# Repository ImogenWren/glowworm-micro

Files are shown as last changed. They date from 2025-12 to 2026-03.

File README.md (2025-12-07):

glowworm-logo-export

# glowworm-micro

Project to build a small battery powered handheld lighting controller for creative macro photography

## Project Due Data: 25/12/25

## Desired Features
- Arduino IoT33 Controller (could be ported to ESP32)
- 1S Lipo battery pack with charger
- Power on and off device using external interrupts
- Rotary Encoder for changing values

- Buttons to select parameter
- Detachable WS2821 Led Strip with 3D printed diffuser options
- 3D printed & ergonomic case
- fastLED library

- 2 Channel Lighting, each channel will have independent
    - Hue
    - Saturation
    - Brightness

Additional control ->  blend mode
- Unblended -> Colours remain seperate
- Direct Blend ->  blend will mix colours directly  
- Colour wheel short blend -> two channels will blend via the shortest route around the colour wheel between them
- colour wheel long blend -> two channels will blend via the longest path around the colour wheel

## Strech Goals
- Save & Recall current settings on shutdown/powerup
- OLED screen displaying all parameters
- highlight currently selected parameter
- Battery indicator
- PCB for control system
- PCB for LED Strip
- Advanced colour palettes



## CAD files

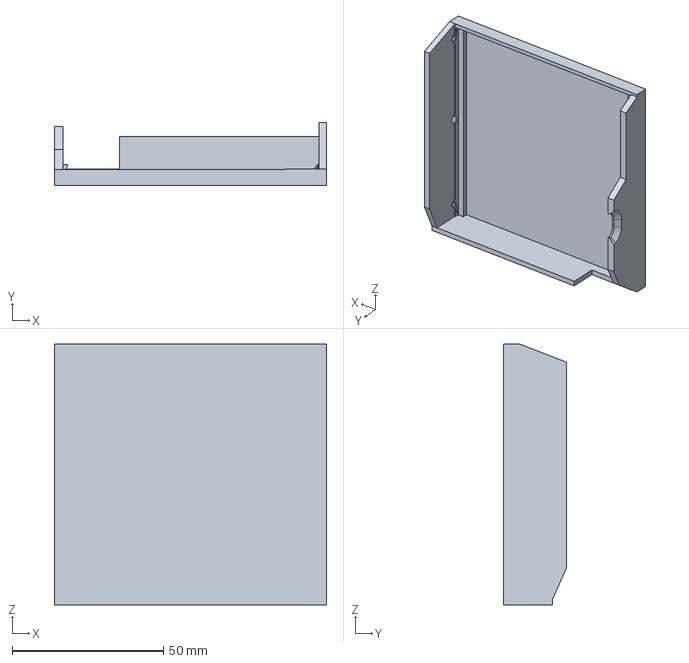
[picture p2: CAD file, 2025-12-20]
CAD/prototyping/glowworm-case-bottom.stp
89.8 x 20.9 x 86.2 mm

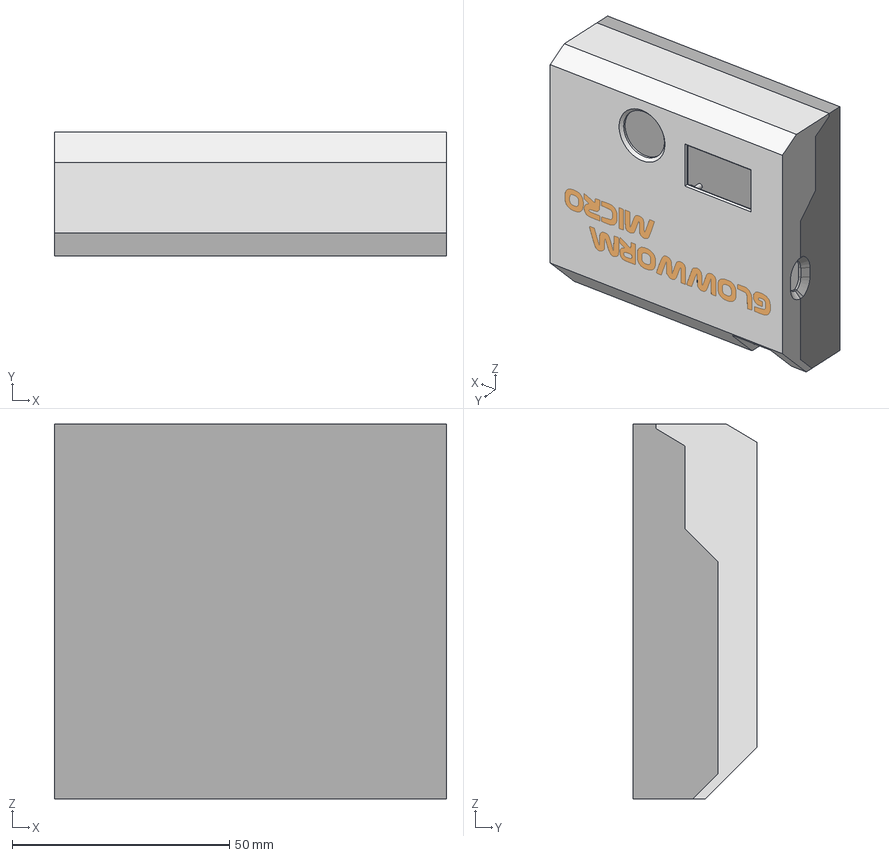
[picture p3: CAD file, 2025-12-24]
CAD/V3-glowworm-CAD.stp
90.2 x 28.5 x 86.2 mm

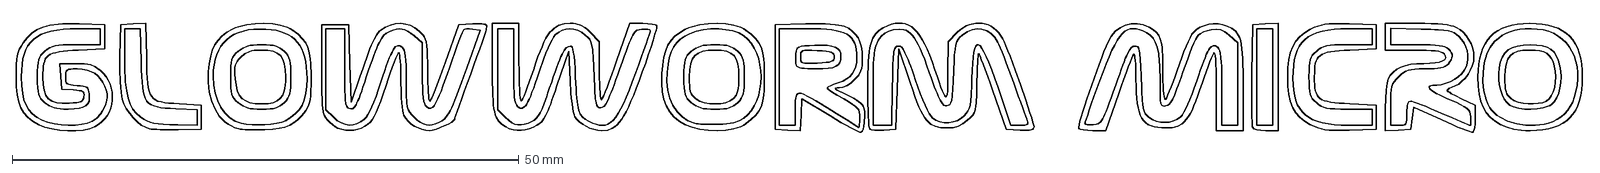
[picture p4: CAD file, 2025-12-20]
docs/glowworm-logo.dxf
154.7 x 11.5 mm

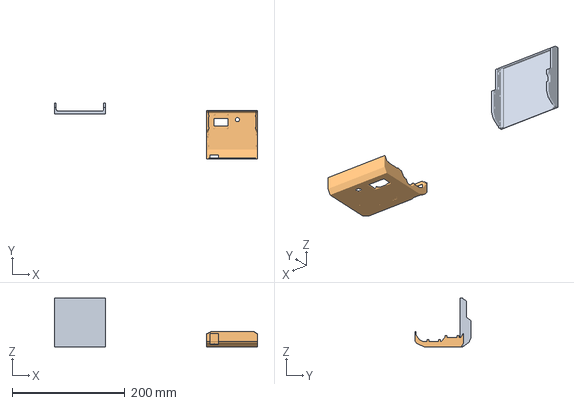
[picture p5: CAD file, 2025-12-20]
CAD/glowworm-case-test-print.3mf
360.3 x 99.0 x 86.2 mm

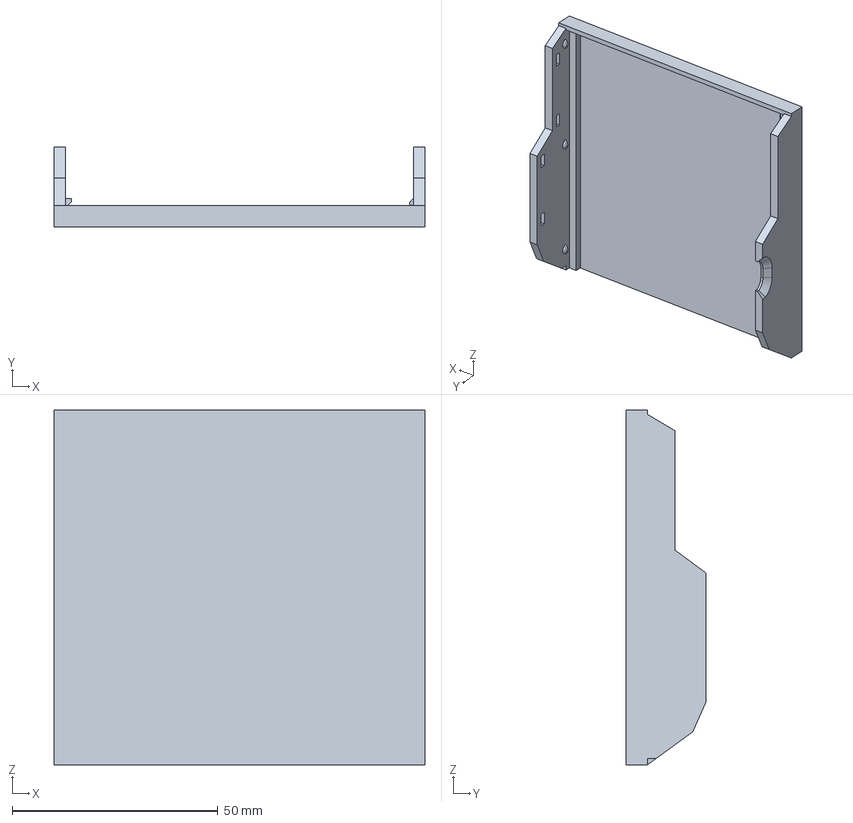
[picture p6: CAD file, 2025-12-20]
CAD/glowworm-case-bottom-V1.stp
90.2 x 19.5 x 86.2 mm

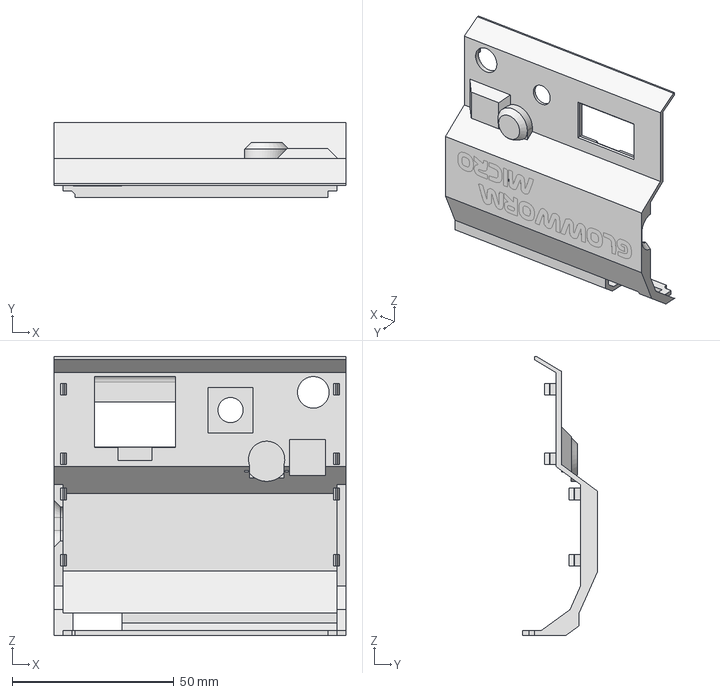
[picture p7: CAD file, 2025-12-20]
CAD/glowworm-case-lid-V1.stp
90.2 x 23.1 x 86.2 mm

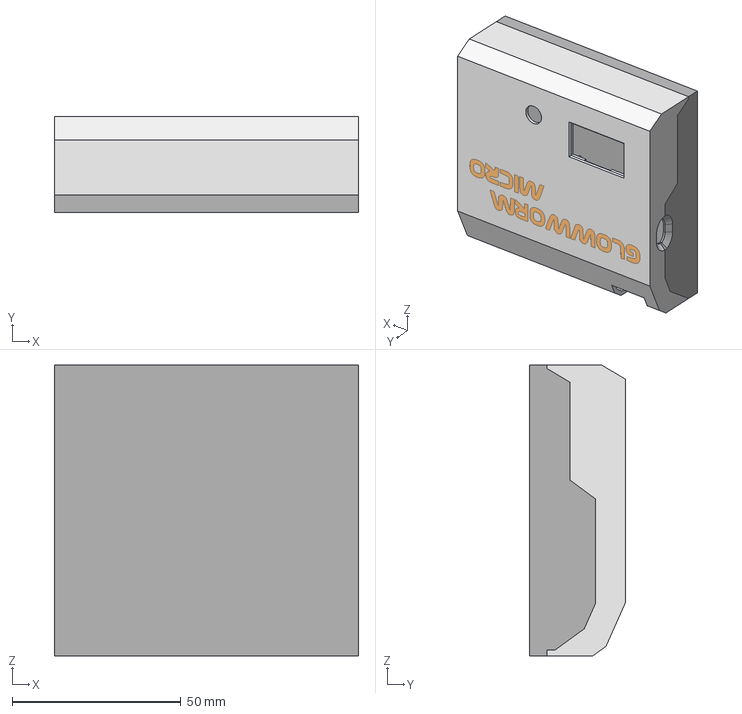
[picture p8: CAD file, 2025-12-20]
CAD/V2-glowworm-case.stp
90.2 x 28.5 x 86.2 mm

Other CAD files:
CAD/OldVersions/V2-glowworm-CAD.0008.ipt
CAD/OldVersions/V3-glowworm-CAD.0017.ipt
CAD/OldVersions/glowworm-CAD.0032.ipt
CAD/V2-glowworm-CAD.ipt
CAD/V2-glowworm-case.3mf
CAD/V3-glowworm-CAD.3mf
CAD/V3-glowworm-CAD.ipt
CAD/glowworm-CAD.ipt
CAD/prototyping/glowworm-case-bottom.3mf

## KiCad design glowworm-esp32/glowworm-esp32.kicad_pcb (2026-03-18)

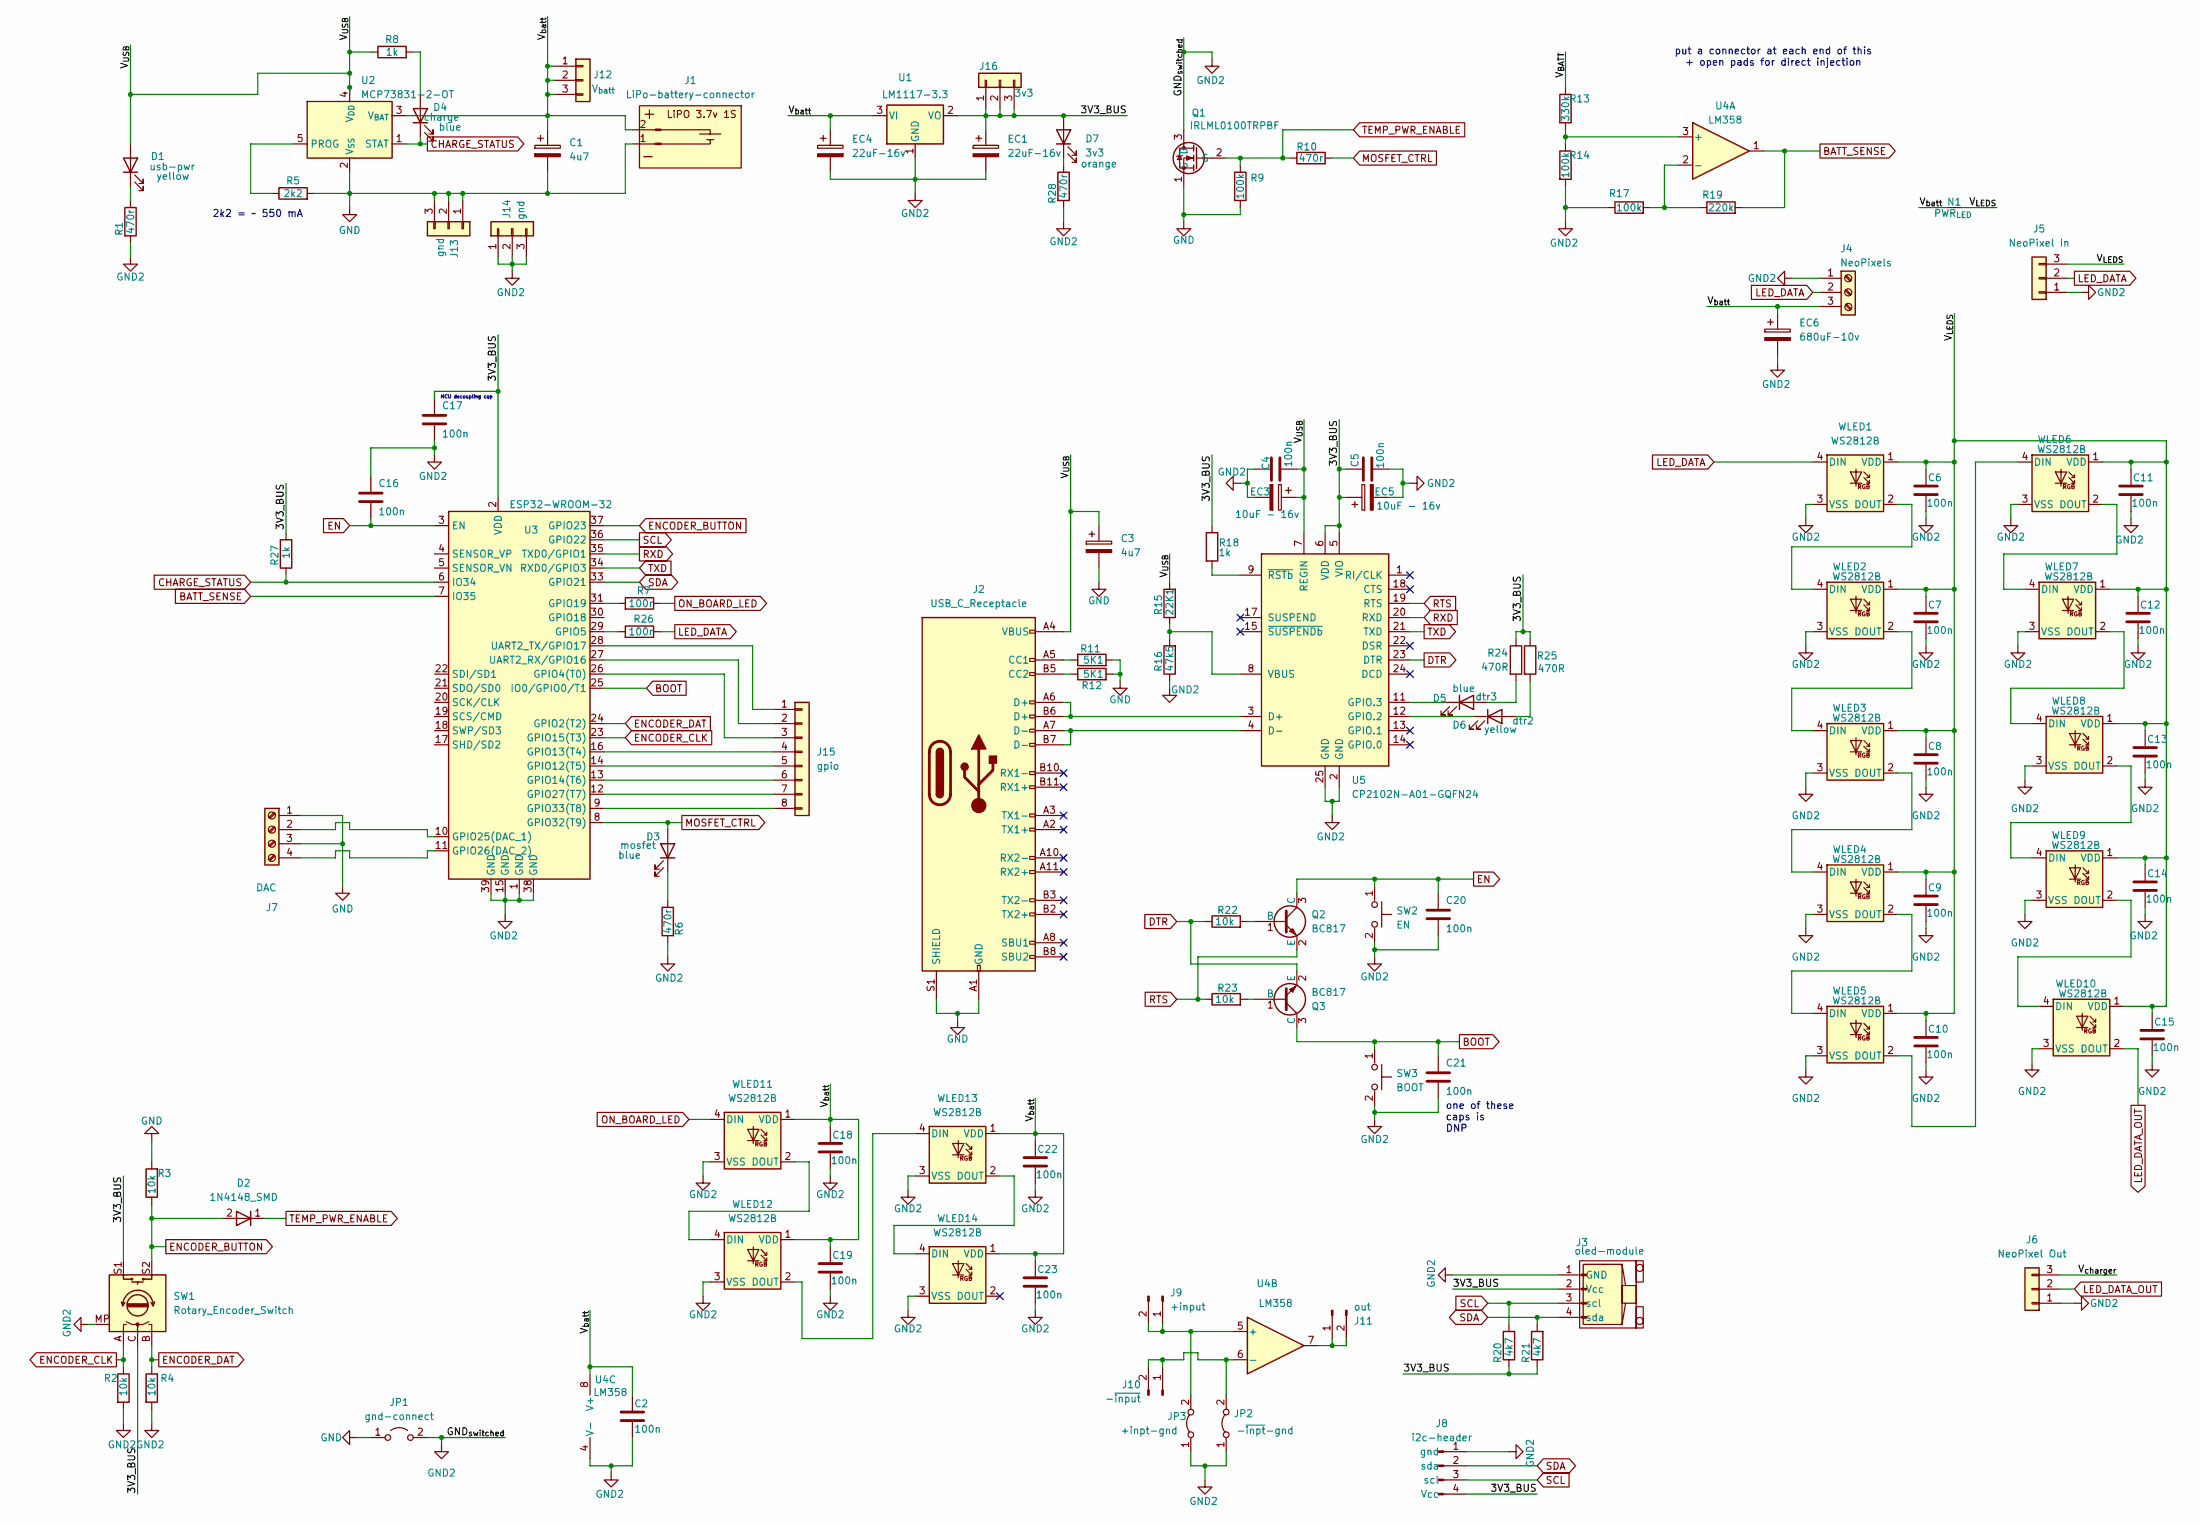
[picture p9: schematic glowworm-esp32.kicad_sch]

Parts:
C1, C3: 4u7; CP_EIA-2012-12_Kemet-R_Pad1.30x1.05mm_HandSolder; JLCpart C1954175
C2, C4, C5, C6, C7, C8, C9, C10, C11, C12, C13, C14, C15, C16, C17, C18, C19, C20, C21, C22, C23: 100n; C_0603_1608Metric_Pad1.08x0.95mm_HandSolder; JLCpart C779975
D1: usb-pwr; D_0603_1608Metric_Pad1.05x0.95mm_HandSolder; JLCpart C84261
D2: 1N4148_SMD; D_MiniMELF_kawaii
D3: mosfet; D_0603_1608Metric_Pad1.05x0.95mm_HandSolder; JLCpart C84259
D4: charge; D_0603_1608Metric_Pad1.05x0.95mm_HandSolder; JLCpart C84259
D5: dtr3; D_0603_1608Metric_Pad1.05x0.95mm_HandSolder; JLCpart C84259
D6: dtr2; D_0603_1608Metric_Pad1.05x0.95mm_HandSolder; JLCpart C84261
D7: 3v3; D_0805_2012Metric_Pad1.15x1.40mm_HandSolder
EC1, EC4: 22uF-16v; CP_Elec_4x5.4; JLCpart C3356
EC3, EC5: 10uF - 16v; CP_Elec_4x5.4; JLCpart C3357
EC6: 680uF-10v; CP_Elec_10x10; JLCpart C225872
J1: LiPo-battery-connector; Molex_KK-254_AE-6410-02A_1x02_P2.54mm_Vertical_copy
J2: USB_C_Receptacle; USB_C_Receptacle_GCT_USB4105-xx-A_16P_TopMnt_Horizontal; JLCpart C134092
J3: oled-module; oled-screen-i2c
J4: NeoPixels; TerminalBlock_01_03_medium_5.008mm
J5: NeoPixel In; PinHeader_1x03_P2.54mm_Vertical
J6: NeoPixel Out; PinHeader_1x03_P2.54mm_Vertical
J7: DAC; TerminalBlock_Phoenix_MPT-0,5-4-2.54_1x04_P2.54mm_Horizontal
J8: i2c-header; i2c-pin-header-A
J9: +input; PinHeader_1x02_P2.54mm_Vertical
J10: -~{input}; PinHeader_1x02_P2.54mm_Vertical
J11: out; PinHeader_1x02_P2.54mm_Vertical
J12: V_{batt}; PinHeader_1x03_P2.54mm_Vertical
J13, J14: gnd; PinHeader_1x03_P2.54mm_Vertical
J15: gpio; PinHeader_1x08_P2.54mm_Vertical
J16: 3v3; PinHeader_1x03_P2.54mm_Vertical
JP1: gnd-connect; SolderJumper-2_P1.3mm_Open_RoundedPad1.0x1.5mm
JP2: -~{inpt}-gnd; SolderJumper-2_P1.3mm_Bridged_RoundedPad1.0x1.5mm
JP3: +inpt-gnd; SolderJumper-2_P1.3mm_Bridged_RoundedPad1.0x1.5mm
N1: PWR_{LED}; NetTie-2_SMD_Pad0.5mm
Q1: IRLML0100TRPBF; SOT-23
Q2, Q3: BC817; SOT-23; JLCpart C2137
R1, R6, R10, R28: 470r; R_0603_1608Metric_Pad0.98x0.95mm_HandSolder
R2, R3, R4, R22, R23: 10k; R_0603_1608Metric_Pad0.98x0.95mm_HandSolder
R5: 2k2; R_0603_1608Metric_Pad0.98x0.95mm_HandSolder
R7, R26: 100r; R_0603_1608Metric_Pad0.98x0.95mm_HandSolder
R8, R18, R27: 1k; R_0603_1608Metric_Pad0.98x0.95mm_HandSolder
R9, R14, R17: 100k; R_0603_1608Metric_Pad0.98x0.95mm_HandSolder
R11, R12: 5K1; R_0603_1608Metric_Pad0.98x0.95mm_HandSolder
R13: 330k; R_0603_1608Metric_Pad0.98x0.95mm_HandSolder
R15: 22K1; R_0603_1608Metric_Pad0.98x0.95mm_HandSolder
R16: 47k5; R_0603_1608Metric_Pad0.98x0.95mm_HandSolder
R19: 220k; R_0603_1608Metric_Pad0.98x0.95mm_HandSolder
R20, R21: 4k7; R_0603_1608Metric_Pad0.98x0.95mm_HandSolder
R24, R25: 470R; R_0603_1608Metric_Pad0.98x0.95mm_HandSolder
SW1: Rotary_Encoder_Switch; RotaryEncoder_Alps_EC12E-Switch_Vertical_H20mm
SW2: EN; SW_SPST_EVQPE1; JLCpart C699451
SW3: BOOT; SW_SPST_EVQPE1; JLCpart C699451
U1: LM1117-3.3; SOT-223-3_TabPin2_1
U2: MCP73831-2-OT; SOT-23-5; JLCpart C424093
U3: ESP32-WROOM-32; JLCpart C473012 - C529577
U4: LM358; SOIC-8_3.9x4.9mm_P1.27mm
U5: CP2102N-A01-GQFN24; QFN-24-1EP_4x4mm_P0.5mm_EP2.6x2.6mm
WLED1, WLED2, WLED3, WLED4, WLED5, WLED6, WLED7, WLED8, WLED9, WLED10, WLED11, WLED12, WLED13, WLED14: WS2812B; LED_WS2812B_PLCC4_5.0x5.0mm_P3.2mm; JLCpart C2920042

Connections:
/3V3_BUS: C5.1, C17.1, D7.2 (A), EC1.1, EC5.1, J3.2 (Vcc), J8.4 (Vcc), J16.1, J16.2, J16.3, R18.1, R20.1, R21.1, R24.1, R25.1, R27.2, SW1.C, SW1.S1, U1.2 (VO), U3.2 (VDD), U5.5 (VIO), U5.6 (VDD)
/V_{BATT}: R13.1
/V_{LEDS}: C6.1, C7.1, C8.1, C9.1, C10.1, C11.1, C12.1, C13.1, C14.1, C15.1, J5.3, N1.2 (C), WLED1.1 (VDD), WLED2.1 (VDD), WLED3.1 (VDD), WLED4.1 (VDD), WLED5.1 (VDD), WLED6.1 (VDD), WLED7.1 (VDD), WLED8.1 (VDD), WLED9.1 (VDD), WLED10.1 (VDD)
/V_{USB}: C3.1, C4.2, D1.2 (A), EC3.1, J2.A4 (VBUS), J2.A9 (VBUS), J2.B4 (VBUS), J2.B9 (VBUS), R8.1, R15.2, U2.4 (V_{DD}), U5.7 (REGIN)
/V_{batt}: C1.1, C2.1, C18.1, C19.1, C22.1, C23.1, EC4.1, EC6.1, J1.2, J4.3 (Pin_1), J12.1, J12.2, J12.3, N1.1 (A), U1.3 (VI), U2.3 (V_{BAT}), U4.8 (V+), WLED11.1 (VDD), WLED12.1 (VDD), WLED13.1 (VDD), WLED14.1 (VDD)
/V_{charger}: J6.3
BATT_SENSE: R19.2, U3.7 (IO35), U4.1
BOOT: C21.1, Q3.3 (C), SW3.1, U3.25 (IO0/GPIO0/T1)
CHARGE_STATUS: D4.1 (K), R27.1, U2.1 (STAT), U3.6 (IO34)
DTR: Q3.2 (E), R22.1, U5.23 (DTR)
EN: C16.2, C20.1, Q2.3 (C), SW2.1, U3.3 (EN)
ENCODER_BUTTON: D2.2 (A), R3.1, SW1.S2, U3.37 (GPIO23)
ENCODER_CLK: R2.1, SW1.A, U3.23 (GPIO15(T3))
ENCODER_DAT: R4.1, SW1.B, U3.24 (GPIO2(T2))
GND: C1.2, C3.2, J1.1, J2.A1 (GND), J2.A12 (GND), J2.B1 (GND), J2.B12 (GND), J2.S1 (SHIELD), J7.1, J7.3, J13.1, J13.2, J13.3, JP1.1 (A), Q1.1 (S), R3.2, R5.2, R9.2, R11.2, R12.2, U2.2 (V_{SS})
GND2: C2.2, C4.1, C5.2, C6.2, C7.2, C8.2, C9.2, C10.2, C11.2, C12.2, C13.2, C14.2, C15.2, C16.1, C17.2, C18.2, C19.2, C20.2, C21.2, C22.2, C23.2, EC1.2, EC3.2, EC4.2, EC5.2, EC6.2, J3.1 (GND), J4.1, J5.1, J6.1, J8.1 (gnd), J14.1, J14.2, J14.3, JP1.2 (B), JP2.1 (A), JP3.1 (A), Q1.3 (D), R1.2, R2.2, R4.2, R6.2, R14.2, R16.1, R17.1, R28.2, SW1.MP, SW2.2, SW3.2, U1.1 (GND), U3.1 (GND), U3.15 (GND), U3.38 (GND), U3.39 (GND), U4.4 (V-), U5.2 (GND), U5.25 (GND), WLED1.3 (VSS), WLED2.3 (VSS), WLED3.3 (VSS), WLED4.3 (VSS), WLED5.3 (VSS), WLED6.3 (VSS), WLED7.3 (VSS), WLED8.3 (VSS), WLED9.3 (VSS), WLED10.3 (VSS), WLED11.3 (VSS), WLED12.3 (VSS), WLED13.3 (VSS), WLED14.3 (VSS)
LED_DATA: J4.2, J5.2, R26.1, WLED1.4 (DIN)
LED_DATA_OUT: J6.2, WLED10.2 (DOUT)
MOSFET_CTRL: D3.2 (A), R10.2, U3.8 (GPIO32(T9))
unnamed: D1.1 (K), R1.1
unnamed: D3.1 (K), R6.1
unnamed: D4.2 (A), R8.2
unnamed: D5.2 (A), R24.2
unnamed: D5.1 (K), U5.11 (GPIO.3)
unnamed: D6.2 (A), R25.2
unnamed: D6.1 (K), U5.12 (GPIO.2)
unnamed: D7.1 (K), R28.1
unnamed: J2.A5 (CC1), R11.1
unnamed: J2.B5 (CC2), R12.1
unnamed: J7.2, U3.10 (GPIO25(DAC_1))
unnamed: J7.4, U3.11 (GPIO26(DAC_2))
unnamed: J9.1, J9.2, JP3.2 (B), U4.5 (+)
unnamed: J10.1, J10.2, JP2.2 (B), U4.6 (-)
unnamed: J11.1, J11.2, U4.7
unnamed: J15.1, U3.28 (UART2_TX/GPIO17)
unnamed: J15.2, U3.27 (UART2_RX/GPIO16)
unnamed: J15.3, U3.26 (GPIO4(T0))
unnamed: J15.4, U3.16 (GPIO13(T4))
unnamed: J15.5, U3.14 (GPIO12(T5))
unnamed: J15.6, U3.13 (GPIO14(T6))
unnamed: J15.7, U3.12 (GPIO27(T7))
unnamed: J15.8, U3.9 (GPIO33(T8))
unnamed: Q2.1 (B), R22.2
unnamed: Q3.1 (B), R23.2
unnamed: R5.1, U2.5 (PROG)
unnamed: R26.2, U3.29 (GPIO5)
unnamed: R7.2, U3.31 (GPIO19)
unnamed: R13.2, R14.1, U4.3 (+)
unnamed: R17.2, R19.1, U4.2 (-)
unnamed: J2.A6 (D+), J2.B6 (D+), U5.3 (D+)
unnamed: J2.A7 (D-), J2.B7 (D-), U5.4 (D-)
unnamed: R15.1, R16.2, U5.8 (VBUS)
unnamed: R18.2, U5.9 (~RSTb)
unnamed: WLED1.2 (DOUT), WLED2.4 (DIN)
unnamed: WLED2.2 (DOUT), WLED3.4 (DIN)
unnamed: WLED3.2 (DOUT), WLED4.4 (DIN)
unnamed: WLED4.2 (DOUT), WLED5.4 (DIN)
unnamed: WLED5.2 (DOUT), WLED6.4 (DIN)
unnamed: WLED6.2 (DOUT), WLED7.4 (DIN)
unnamed: WLED7.2 (DOUT), WLED8.4 (DIN)
unnamed: WLED8.2 (DOUT), WLED9.4 (DIN)
unnamed: WLED9.2 (DOUT), WLED10.4 (DIN)
unnamed: WLED11.2 (DOUT), WLED12.4 (DIN)
unnamed: WLED12.2 (DOUT), WLED13.4 (DIN)
unnamed: WLED13.2 (DOUT), WLED14.4 (DIN)
ON_BOARD_LED: R7.1, WLED11.4 (DIN)
RTS: Q2.2 (E), R23.1, U5.19 (RTS)
RXD: U3.35 (TXD0/GPIO1), U5.20 (RXD)
SCL: J3.3 (scl), J8.3 (scl), R20.2, U3.36 (GPIO22)
SDA: J3.4 (sda), J8.2 (sda), R21.2, U3.33 (GPIO21)
TEMP_PWR_ENABLE: D2.1 (K), Q1.2 (G), R9.1, R10.1
TXD: U3.34 (RXD0/GPIO3), U5.21 (TXD)

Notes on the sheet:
put a connector at each end of this + open pads for direct injection
MCU decoupling cap
one of these caps is DNP
2k2 = ~ 550 mA

Board: 2 copper layers, 108 parts (0 on the bottom side), 70 nets, no tracks yet.

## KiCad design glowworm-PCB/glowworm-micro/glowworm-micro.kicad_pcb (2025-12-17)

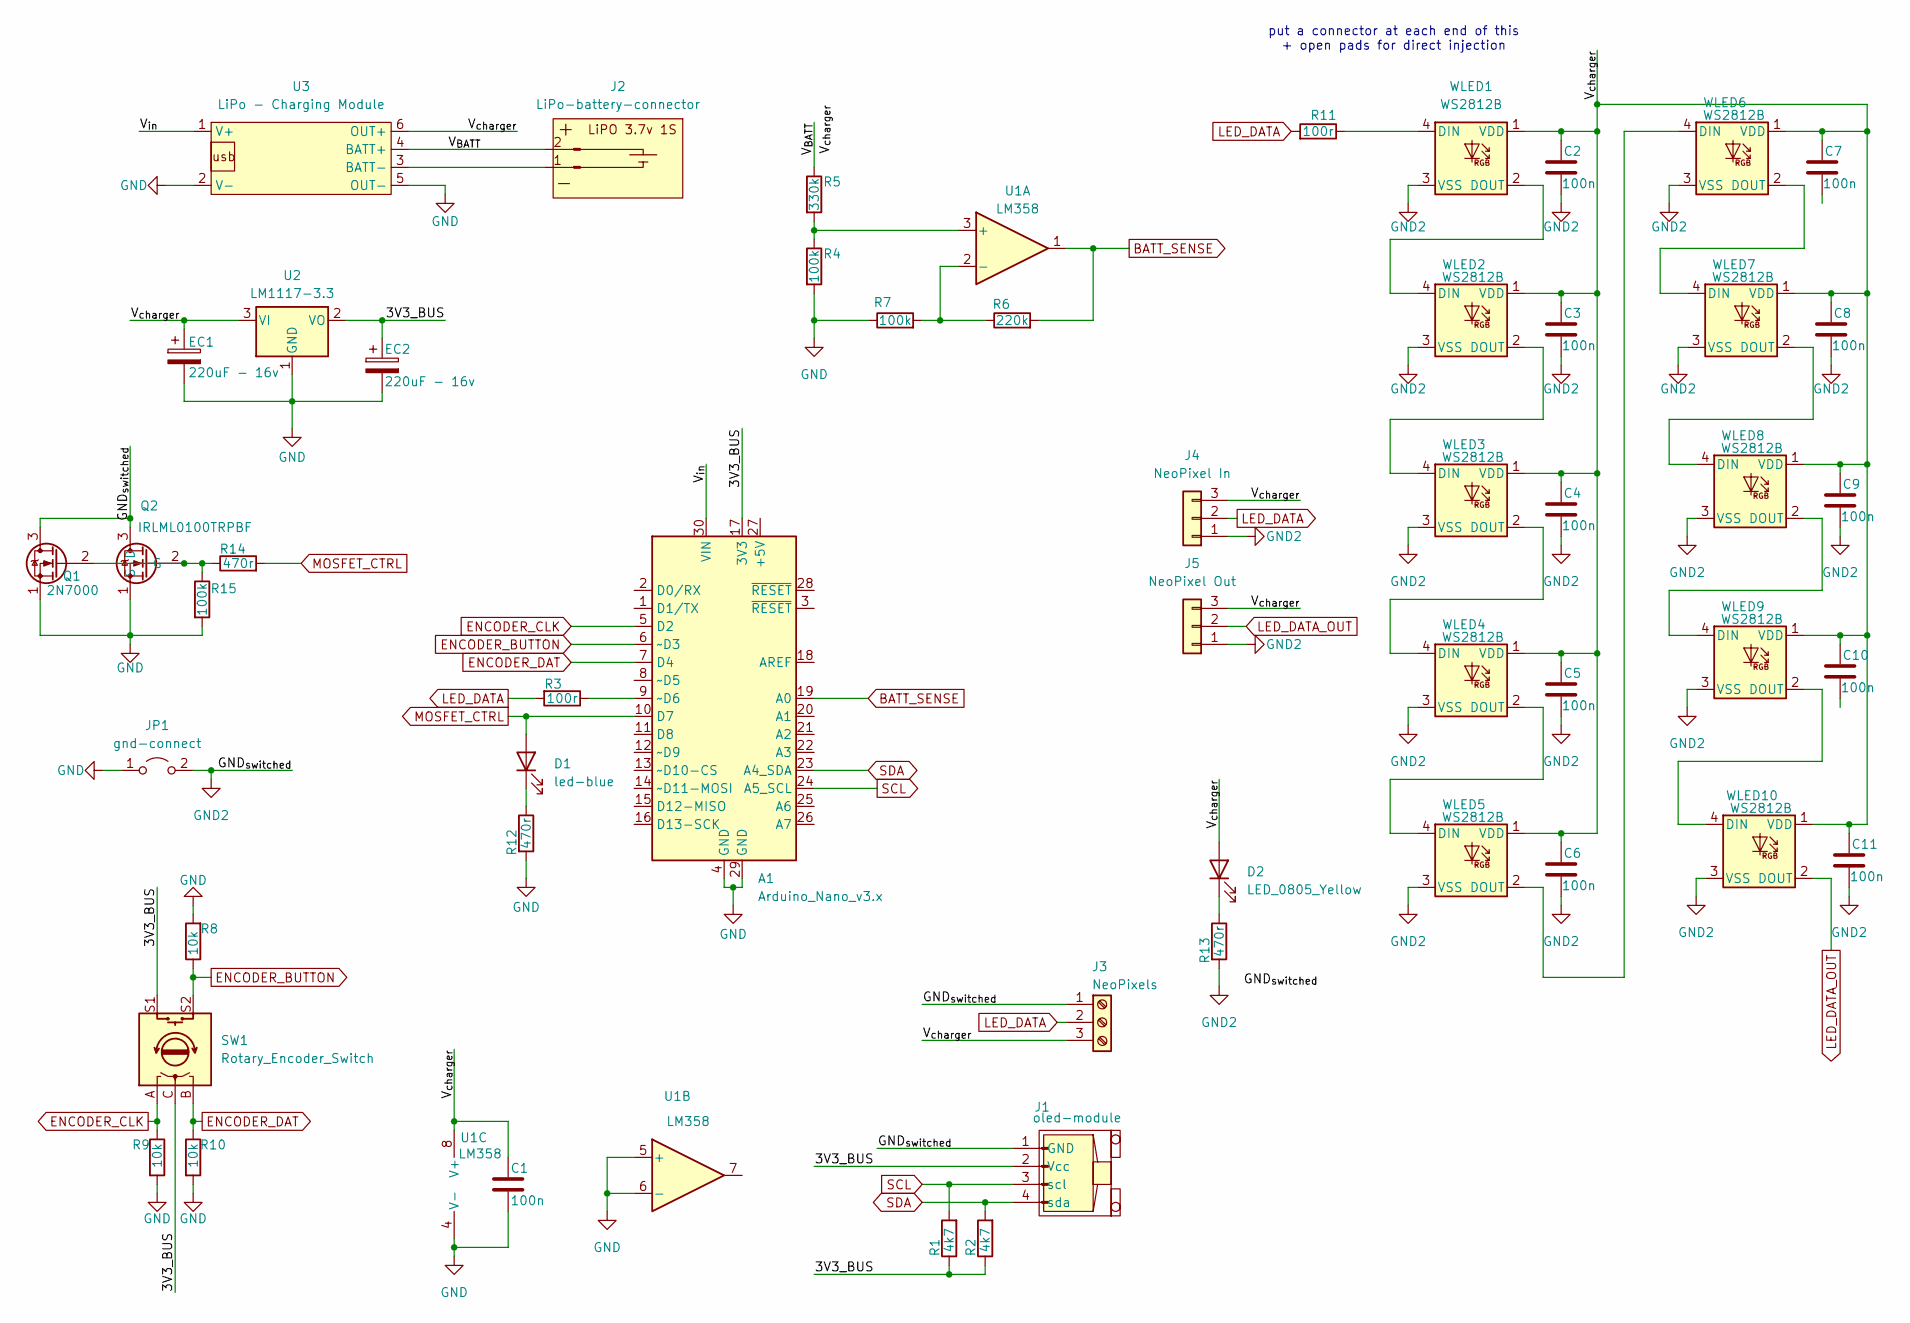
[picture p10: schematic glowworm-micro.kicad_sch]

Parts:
A1: Arduino_Nano_v3.x; Arduino_Nano
C1, C2, C3, C4, C5, C6, C7, C8, C9, C10, C11: 100n; C_0603_1608Metric_Pad1.08x0.95mm_HandSolder; JLCpart C779975
D1: led-blue; D_0805_2012Metric_Pad1.15x1.40mm_HandSolder; JLCpart C84259
D2: LED_0805_Yellow; D_0805_2012Metric_Pad1.15x1.40mm_HandSolder; JLCpart C84261
EC1, EC2: 220uF - 16v; CP_Elec_6.3x7.7; JLCpart C4747974
J1: oled-module; oled-screen-i2c
J2: LiPo-battery-connector; Molex_KK-254_AE-6410-02A_1x02_P2.54mm_Vertical_copy
J3: NeoPixels; TerminalBlock_01_03_medium_5.008mm
J4: NeoPixel In; PinHeader_1x03_P2.54mm_Vertical
J5: NeoPixel Out; PinHeader_1x03_P2.54mm_Vertical
JP1: gnd-connect; SolderJumper-2_P1.3mm_Open_RoundedPad1.0x1.5mm
Q1: 2N7000; TO-92_Inline
Q2: IRLML0100TRPBF; SOT-23
R1, R2: 4k7; R_0603_1608Metric_Pad0.98x0.95mm_HandSolder
R3, R11: 100r; R_0603_1608Metric_Pad0.98x0.95mm_HandSolder
R4, R7, R15: 100k; R_0603_1608Metric_Pad0.98x0.95mm_HandSolder
R5: 330k; R_0603_1608Metric_Pad0.98x0.95mm_HandSolder
R6: 220k; R_0603_1608Metric_Pad0.98x0.95mm_HandSolder
R8, R9, R10: 10k; R_0603_1608Metric_Pad0.98x0.95mm_HandSolder
R12, R13, R14: 470r; R_0603_1608Metric_Pad0.98x0.95mm_HandSolder
SW1: Rotary_Encoder_Switch; RotaryEncoder_Alps_EC12E-Switch_Vertical_H20mm
U1: LM358; SOIC-8_3.9x4.9mm_P1.27mm
U2: LM1117-3.3; SOT-223-3_TabPin2_1
U3: LiPo - Charging Module; lipo-charging-module
WLED1, WLED2, WLED3, WLED4, WLED5, WLED6, WLED7, WLED8, WLED9, WLED10: WS2812B; LED_WS2812B_PLCC4_5.0x5.0mm_P3.2mm; JLCpart C2920042

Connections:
/3V3_BUS: A1.17 (3V3), EC2.1, J1.2 (Vcc), R1.1, R2.1, SW1.C, SW1.S1, U2.2 (VO)
/V_{BATT}: J2.2, R5.1, U3.4 (BATT+)
/V_{charger}: C1.1, C2.1, C3.1, C4.1, C5.1, C6.1, C7.1, C8.1, C9.1, C10.1, C11.1, D2.2 (A), EC1.1, J3.3 (Pin_1), J4.3, J5.3, U1.8 (V+), U2.3 (VI), U3.6 (OUT+), WLED1.1 (VDD), WLED2.1 (VDD), WLED3.1 (VDD), WLED4.1 (VDD), WLED5.1 (VDD), WLED6.1 (VDD), WLED7.1 (VDD), WLED8.1 (VDD), WLED9.1 (VDD), WLED10.1 (VDD)
/V_{in}: A1.30 (VIN), U3.1 (V+)
BATT_SENSE: A1.19 (A0), R6.2, U1.1
ENCODER_BUTTON: A1.6 (~D3), R8.1, SW1.S2
ENCODER_CLK: A1.5 (D2), R9.1, SW1.A
ENCODER_DAT: A1.7 (D4), R10.1, SW1.B
GND: A1.4 (GND), A1.29 (GND), C1.2, EC1.2, EC2.2, JP1.1 (A), Q1.1 (S), Q2.1 (S), R4.2, R7.1, R8.2, R9.2, R10.2, R12.2, R15.2, U1.4 (V-), U1.5 (+), U1.6 (-), U2.1 (GND), U3.2 (V-), U3.5 (OUT-)
GND2: C2.2, C3.2, C4.2, C5.2, C6.2, C8.2, C9.2, C11.2, J1.1 (GND), J3.1, J4.1, J5.1, JP1.2 (B), Q1.3 (D), Q2.3 (D), R13.2, WLED1.3 (VSS), WLED2.3 (VSS), WLED3.3 (VSS), WLED4.3 (VSS), WLED5.3 (VSS), WLED6.3 (VSS), WLED7.3 (VSS), WLED8.3 (VSS), WLED9.3 (VSS), WLED10.3 (VSS)
LED_DATA: J3.2, J4.2, R3.2, R11.2
LED_DATA_OUT: J5.2, WLED10.2 (DOUT)
MOSFET_CTRL: A1.10 (D7), D1.2 (A), R14.2
unnamed: A1.9 (~D6), R3.1
unnamed: D1.1 (K), R12.1
unnamed: D2.1 (K), R13.1
unnamed: J2.1, U3.3 (BATT-)
unnamed: Q1.2 (G), Q2.2 (G), R14.1, R15.1
unnamed: R4.1, R5.2, U1.3 (+)
unnamed: R6.1, R7.2, U1.2 (-)
unnamed: R11.1, WLED1.4 (DIN)
unnamed: WLED1.2 (DOUT), WLED2.4 (DIN)
unnamed: WLED2.2 (DOUT), WLED3.4 (DIN)
unnamed: WLED3.2 (DOUT), WLED4.4 (DIN)
unnamed: WLED4.2 (DOUT), WLED5.4 (DIN)
unnamed: WLED5.2 (DOUT), WLED6.4 (DIN)
unnamed: WLED6.2 (DOUT), WLED7.4 (DIN)
unnamed: WLED7.2 (DOUT), WLED8.4 (DIN)
unnamed: WLED8.2 (DOUT), WLED9.4 (DIN)
unnamed: WLED9.2 (DOUT), WLED10.4 (DIN)
SCL: A1.24 (A5_SCL), J1.3 (scl), R1.2
SDA: A1.23 (A4_SDA), J1.4 (sda), R2.2

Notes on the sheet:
put a connector at each end of this + open pads for direct injection

Board: 2 copper layers, 49 parts (0 on the bottom side), 31 nets, no tracks yet.

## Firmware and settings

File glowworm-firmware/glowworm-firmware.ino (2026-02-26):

/* GlowWorm Micro -> Mini lighting controller for creative Macro Photography



Example functions for printing bitmap images to SSD1306 OLED screen
// Converted using https://mischianti.org/images-to-byte-array-online-converter-cpp-arduino/
*/

/* Changelog

*/



#include "globals.h"




ledObject ledGRN(GREEN_LED_PIN);
ledObject ledRED(RED_LED_PIN);
buttonObject button2(BUTTON_PIN, BUTTON_PULL_HIGH);


void setup() {
  // Setup Serial
  Serial.begin(115200);
  Serial.println(F("\nGlowWorm Micro"));
  Serial.println(F("lighting controller"));
  Serial.println(F("Waking Up..."));
  //digitalWrite(MOSFET_CTRL, true);
  // delay(3000);

  // set up IO
  pinMode(BUTTON_PIN, INPUT);
  pinMode(MOSFET_PIN, OUTPUT);
  ledGRN.begin(false);
  ledRED.begin(false);
  pinMode(ENCODER_CLK, INPUT);
  pinMode(ENCODER_DAT, INPUT);

  // Check whether button is being held
  uint32_t power_on_time_ms = millis();
  bool still_asleep = true;
  while (still_asleep) {

    if (millis() - power_on_time_ms >= 2000) {
      still_asleep = false;
      Serial.println("Turning On");
      digitalWrite(MOSFET_PIN, HIGH);
      ledGRN.turnOn();
    }
  }
  button2.begin();
  ledRED.startBlink(1000, 1000);

  indicator.begin(150);
  indicator.callBlink(10, 40, 130);

  // Setup IO Pins
  // delay(1000);
  show_splash();
  // Set up button Object
  button.begin();


  // use interrupt for CLK pin is enough
  // call ISR_encoder() when CLK pin changes from LOW to HIGH
  attachInterrupt(digitalPinToInterrupt(ENCODER_CLK), ISR_encoder, RISING);
  // Wake on rising edge (HIGH)
  // LowPower.attachInterruptWakeup(ENCODER_BUTTON_EXTINT8, onWakeupISR, RISING);



  // set up LED string
  FastLED.addLeds<LED_TYPE, LED_DATA_PIN, COLOR_ORDER>(leds, NUM_LEDS).setCorrection(TypicalLEDStrip);
  FastLED.setBrightness(START_BRIGHTNESS);


  // Set up i2c slave to handle requests from Raspberry Pi
  // Wire.begin(I2C_ADDRESS);
  // Wire.onRequest(requestEvent);
}



void loop() {
  // sample battery voltage
  batteryMonitor();

  // Sample OLED Button
  button.buttonLoop(WAKE_UP_TIME);
  // SBC power cycle trigger
  if (button.shortPress) {
    select_mode = !select_mode;
    button.buttonReset();
  }

  // if (button.longPress) {
  // do shutdown
  //    indicator.callBlink(10, 40, 130);
  //   onShutdown();
  //   button.buttonReset();
  // }
  // check_wake_button();
  // unblock_sleep();


  update_oled();


  if (ISR_triggered) {
    if (select_mode) {
      active_stat = encoder_rollover(active_stat, direction, 0, 7);
    } else {
      // adjust the live value

      if (active_stat == 0) {
        currentLED.num_leds = encoder_rollover(currentLED.num_leds, direction, 0, MAX_LED_LENGTH);
        num_leds_updated = true;
      } else if (active_stat == 1) {
        currentLED.blend = encoder_rollover(currentLED.blend, direction, 0, WHEEL_LONG);
      } else if (active_stat == 2) {
        currentLED.ch_A_hue = encoder_rollover(currentLED.ch_A_hue, direction, 0, 255);
      } else if (active_stat == 3) {
        currentLED.ch_A_sat = encoder_rollover(currentLED.ch_A_sat, direction, 0, 255);
      } else if (active_stat == 4) {
        currentLED.ch_A_bright = encoder_rollover(currentLED.ch_A_bright, direction, 0, 255);
      } else if (active_stat == 5) {
        currentLED.ch_B_hue = encoder_rollover(currentLED.ch_B_hue, direction, 0, 255);
      } else if (active_stat == 6) {
        currentLED.ch_B_sat = encoder_rollover(currentLED.ch_B_sat, direction, 0, 255);
      } else if (active_stat == 7) {
        currentLED.ch_B_bright = encoder_rollover(currentLED.ch_B_bright, direction, 0, 255);
      } else if (active_stat > 7) {
        Serial.println(F("ERROR, illegal active stat"));
      }

      updateLEDs = true;
    }
    ISR_triggered = false;
  }

  if (num_leds_updated) {
    for (int i = currentLED.num_leds; i < MAX_LED_LENGTH; i++) {
      leds[i] = CHSV(0, 0, 0);  // turn all the remaining LEDs back, rather than just have them not update
    }
    num_leds_updated = false;
  }

  if (updateLEDs) {
    // then update the LED outputs depending on blend mode
    // if blend mode is NONE
    if (currentLED.blend == NO_BLEND) {
      for (int i = 0; i < currentLED.num_leds / 2; ++i) {
        leds[i] = CHSV(currentLED.ch_A_hue, currentLED.ch_A_sat, currentLED.ch_A_bright);
      }
      for (int i = currentLED.num_leds / 2; i < currentLED.num_leds; ++i) {
        leds[i] = CHSV(currentLED.ch_B_hue, currentLED.ch_B_sat, currentLED.ch_B_bright);
      }
    } else if (currentLED.blend == DIRECT_BLEND) {
      // use pallets?
      //  for (int i = 0; i < currentLED.num_leds / 2; i++) {
      //   outputPalette[0] = CHSV(currentLED.ch_A_hue, currentLED.ch_A_sat, currentLED.ch_A_bright);  // fill entire pallette with both colours
      // }
      // for (int i = currentLED.num_leds / 2; i < currentLED.num_leds; i++) {
      //  outputPalette[1] = CHSV(currentLED.ch_B_hue, currentLED.ch_B_sat, currentLED.ch_B_bright);
      //  }
      colourA = CHSV(currentLED.ch_A_hue, currentLED.ch_A_sat, currentLED.ch_A_bright);
      colourB = CHSV(currentLED.ch_B_hue, currentLED.ch_B_sat, currentLED.ch_B_bright);
      buildPalette();

      // trying to get a pallette using just the two colours
      for (int i = 0; i < currentLED.num_leds; i++) {
        uint8_t index = map(i, 0, currentLED.num_leds - 1, 0, 255);
        leds[i] = ColorFromPalette(outputPalette, index, currentLED.ch_A_bright, LINEARBLEND_NOWRAP);
      }
    } else if (currentLED.blend == WHEEL_SHORT) {
      colourA = CHSV(currentLED.ch_A_hue, currentLED.ch_A_sat, currentLED.ch_A_bright);
      colourB = CHSV(currentLED.ch_B_hue, currentLED.ch_B_sat, currentLED.ch_B_bright);
      fill_gradient(leds, currentLED.num_leds - 1, colourA, colourB, SHORTEST_HUES);
      //leds[currentLED.num_leds - 1] = CHSV(currentLED.ch_B_hue, currentLED.ch_B_sat, currentLED.ch_B_bright);  // this line makes sure our maths works, the penultamate LED should blend into the last one that is set to the channel B colour
    } else if (currentLED.blend == WHEEL_LONG) {
      colourA = CHSV(currentLED.ch_A_hue, currentLED.ch_A_sat, currentLED.ch_A_bright);
      colourB = CHSV(currentLED.ch_B_hue, currentLED.ch_B_sat, currentLED.ch_B_bright);
      fill_gradient(leds, currentLED.num_leds - 1, colourA, colourB, LONGEST_HUES);
      // leds[currentLED.num_leds - 1] = CHSV(currentLED.ch_B_hue, currentLED.ch_B_sat, currentLED.ch_B_bright);  // this line makes sure our maths works, the penultamate LED should blend into the last one that is set to the channel B colour
    }

    FastLED.show();
    //  // FastLED.delay(1000 / UPDATES_PER_SECOND);
    //  multi_update++;
    //  if (multi_update > 2){
    //     multi_update = 0;
    updateLEDs = false;  // this is here to try and prevent LEDs getting out of sync because of a bad interrupt
    //  }
    // updateLEDs = false;
  }
  if (button2.longPress) {
    display.clearDisplay();
    display.setCursor(25, 30);
    display.print("Powering Off...");
    display.display();
    Serial.println("turning off...");
    ledGRN.turnOff();
    while (digitalRead(BUTTON_PIN)) {
      //wait for system to shutdown
    }
    delay(1300);
    digitalWrite(MOSFET_PIN, LOW);
    button.buttonReset();  // this probably doesnt matter in this topology
  }
  ledRED.performBlink();
  button2.buttonLoop(1500);
  indicator.performBlink();
}



void requestEvent() {  // note try this command on raspberry pi to get data in hex `i2cget -y 1 0x08 0x00 i` then decode hex as UTF-16 big endian
  //  Wire.write(adj_V_buf);
  ///  Wire.write(", ");
  // Wire.write(adj_I_buf);
  // Wire.write(", ");
  // Wire.write(sbc_V_buf);
  // Wire.write(", ");
  // Wire.write(sbc_I_buf);
  //  Wire.write(".\n ");
}

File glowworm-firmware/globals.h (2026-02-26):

#pragma once

#ifndef globals_h
#define globals_h




// External Libraries
#include <SPI.h>
#include <Wire.h>
#include <Adafruit_GFX.h>
#include <Adafruit_SSD1306.h>
#include <FastLED.h>
#include <ledObject.h>
#include <buttonObject.h>
//#include <multiMeter.h>
#include "calibration.h"

#include <ledObject.h>
#include <buttonObject.h>

const int BUTTON_PIN = 23;
const int MOSFET_PIN = 32;

const int GREEN_LED_PIN = 5;
const int RED_LED_PIN = 19;


//#include <Fonts/FreeMonoBold12pt7b.h >
//#include <Fonts/FreeSansBold12pt7b.h >
//#include <Fonts/FreeSansBold9pt7b.h >

//#include <avr/dtostrf.h>  //needed for SAMD21 only


// Configuration
#define SHOW_SPASH_SCREEN true

// IO PINS
// I2C
#define SDA_PIN A4
#define SCL_PIN A5
// Encoder
#define ENCODER_CLK 2
#define ENCODER_DAT 4
// smart LEDS
#define LED_DATA_PIN 14//6
// sleep function vars
#define ENCODER_BUTTON_EXTINT8 3
#define MOSFET_CTRL 7

// Battery Monitor
#define BATTERY_SENSE_PIN A0
//#define INPUT_V_MAX 3.3      // Max Voltage for the ADC Input Pin
//#define ADC_RESOLUTION 10  // Typically 10bit on Arduino Platforms
//#define DO_TABLE_CAL false

#define DIRECTION_CW 1    // clockwise direction
#define DIRECTION_CCW -1  // counter-clockwise direction

#define ENCODER_PPR 600
#define ENCODER_TYPE TWO_WIRE
#define ENCODER_NAME "encoder"

// Button


// LED


#define NUM_LEDS 6
#define START_BRIGHTNESS 200
#define LED_TYPE WS2811
#define COLOR_ORDER GRB
#define UPDATES_PER_SECOND 100
#define MAX_LED_LENGTH 255

//CRGB leds[NUM_LEDS];
CRGB leds[MAX_LED_LENGTH];  // set this for the maximum suitable string, and will only be limited in runtime via user setting ( default 8)





//ledObject indicator(LED_BUILTIN);


//#include <ArduinoLowPower.h>
#define WAKE_UP_TIME 2500

volatile bool wokeFromInterrupt = false;
volatile bool sleep_active = false;

bool sleep_block = false;
unsigned long wake_start;




// ADC Consts
#define CURRENT_ADC_OFFSET 0  //-323
#define CURRENT_I_OFFSET -5

// Timing Consts



// Global Objects
buttonObject button(ENCODER_BUTTON_EXTINT8, BUTTON_PULL_HIGH);
ledObject indicator(LED_BUILTIN);
//multiMeter voltMeter(BATTERY_SENSE_PIN, METER_TYPE, INPUT_V_MAX, ADC_RESOLUTION, DO_TABLE_CAL);
calibration cal;

// OLED
#define SCREEN_WIDTH 128  // OLED display width, in pixels
#define SCREEN_HEIGHT 64  // OLED display height, in pixels

#define OLED_ADDR 0x3C
Adafruit_SSD1306 display(SCREEN_WIDTH, SCREEN_HEIGHT, &Wire, -1);

#if (SSD1306_LCDHEIGHT != 64)
//#error("Height incorrect, please fix Adafruit_SSD1306.h!");
#endif

#include "sleepFunctions.h"

volatile uint8_t encoderVal = 0;
uint8_t buttonPressed = 0;
volatile int direction = DIRECTION_CW;
volatile uint32_t last_time;
volatile bool ISR_triggered = false;

// Consts
//const char SYSTEM_NAME = {"Practable Power Hat V1.0"}
const uint8_t I2C_ADDRESS = 0x08;  // Address of i2c slave (self)

uint8_t active_stat = 0;  // The active high bit highlights the selected sat in the UI
bool select_mode = true;  // when select mode is active, encoder used to select active stat. When false,
// encoder changes value of active stat
bool updateLEDs = true;
uint8_t multi_update = 0;
bool num_leds_updated = true;

// LED data struc -> set up like this to make saving and recalling data from memory easy

// blend modes
typedef enum {
  NO_BLEND,
  DIRECT_BLEND,
  WHEEL_SHORT,
  WHEEL_LONG
} blend_mode;

//blend_mode currentBlend = NO_BLEND;

static char blendNames[][8] = {
  "None",
  "Direct",
  "Short",
  "Long"
};



struct LED_data {  // Channel A
  uint8_t ch_A_hue;
  uint8_t ch_A_sat;
  uint8_t ch_A_bright;
  uint8_t ch_B_hue;
  uint8_t ch_B_sat;
  uint8_t ch_B_bright;
  int8_t blend;
  uint8_t num_leds;
};

LED_data defaultData = {
  100, 255, START_BRIGHTNESS,
  200, 255, START_BRIGHTNESS,
  DIRECT_BLEND, NUM_LEDS
};

LED_data currentLED = defaultData;


// palette blending options
CRGBPalette16 outputPalette;
TBlendType currentBlending = LINEARBLEND_NOWRAP;

CHSV colourA = CHSV(40, 255, 255);
CHSV colourB = CHSV(128, 255, 255);
// Channel A
/*
uint8_t ch_A_hue = 20;
uint8_t ch_A_sat = 255;
uint8_t ch_A_bright = START_BRIGHTNESS;

// Channel B
uint8_t ch_B_hue = 230;
uint8_t ch_B_sat = 255;
uint8_t ch_B_bright = START_BRIGHTNESS;
*/

// All Channels
//uint8_t blend = 0;
//uint8_t num_leds = 6;

#define BATTERY_SAMPLES_REQ 20
uint8_t battery_indicator_level = 0;  // while charging this can cylce from 1 to 3
uint8_t batt_indicator_unsmoothed[BATTERY_SAMPLES_REQ + 2];
uint8_t battery_samples_taken = 0;
int16_t battery_adc = 0;
float batteryVoltage;

// Internal Headers
#include "encoder.h"
#include "batteryMonitor.h"
#include "oled.h"
#include "leds.h"
#include "state_machines.h"
#include "power_sense.h"


#endif

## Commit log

2025-12-12 Working on wake from interrupt example
2025-12-12 shutdown and power on test script is working
2025-12-12 shutdown working, ish, need to fix MOSFET power control hardware
    [globals.h, glowworm-firmware.ino, sleep-mode-testing.ino]
2025-12-17 hardware prototype done
    [glowworm-micro.kicad_pcb, glowworm-micro.kicad_sch]
2025-12-17 battery monitor working
2025-12-20 lots of CAD work
    [V2-glowworm-CAD.0008.ipt, V2-glowworm-CAD.ipt, V2-glowworm-case.stp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]
2025-12-24 updated to case version 3
    [V2-glowworm-case.3mf, V3-glowworm-CAD.0017.ipt, V3-glowworm-CAD.ipt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]
2026-01-01 working on battery monitor tuning
2026-02-26 ported to ESP32
2026-03-18 updates to pcb
    [glowworm-esp32.kicad_pcb, glowworm-esp32.kicad_sch]
